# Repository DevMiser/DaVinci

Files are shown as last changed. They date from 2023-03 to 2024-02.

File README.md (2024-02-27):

Raspberry Pi’s newest OS (Bookworm) released on December 5, 2023, does not work well with this installation.
For best results, use a Raspberry Pi 4 (not a Raspberry Pi 5) and use the legacy 64-bit OS.
Instructions are in the Important - Please Read file on this repository.

DaVinci now uses GPT-4.

Feb. 23, 2024 Update - I added an alternative voice to DaVinci that uses OpenAI’s text-to-speech model instead of Amazon Polly.  The alternative file is called DaVinciAltVoice.py.  If you decide to you use this version, you do not need to create an AWS account.  In the rest of the instructions, you can skip “pip3 install boto” and “pip3 install awscli” and all of step 3 for configuring the AWS interface.  Substitute “DaVinciAltVoice.py” for “DaVinci.py” everywhere it appears in the instructions.

I also added an Italian speaking version - DaVinciItalian.py.  To use it, you must follow the additional instructions in the introductory comments in that program.

DaVinci Small








8A
8B
In10
In11
In12

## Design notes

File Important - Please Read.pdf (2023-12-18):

IMPORTANT – PLEASE READ

Raspberry Pi’s newest OS (Bookworm) released on December 5, 2023, does not work well with this installaon.
For best results, use a Raspberry Pi 4 (not a Raspberry Pi 5) and use the legacy 64-bit OS. To load the legacy OS, use Raspberry Pi Imager and select Raspberry Pi 4 as the Raspberry Pi Device. Aer you select CHOOSE OS under Operang System, select Raspberry Pi OS (other) [Figure 1]. On the next screen, scroll down and select Raspberry Pi OS (Legacy, 64-bit) [Figure 2], and proceed as normal from there.

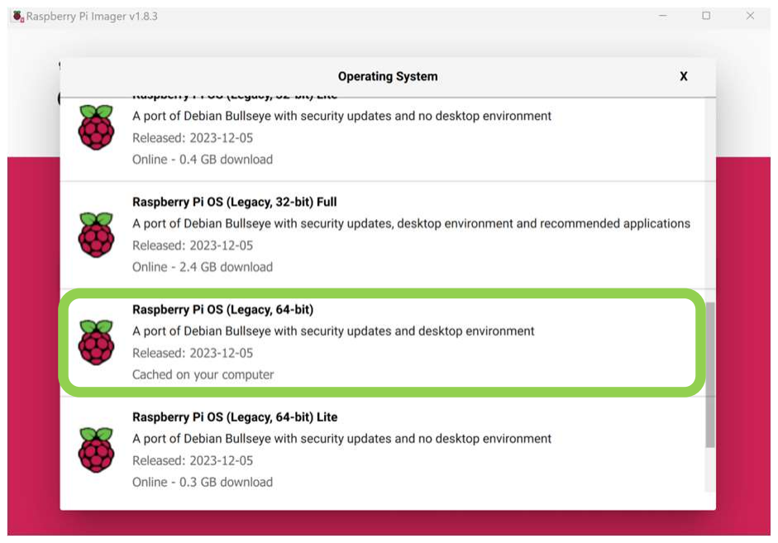
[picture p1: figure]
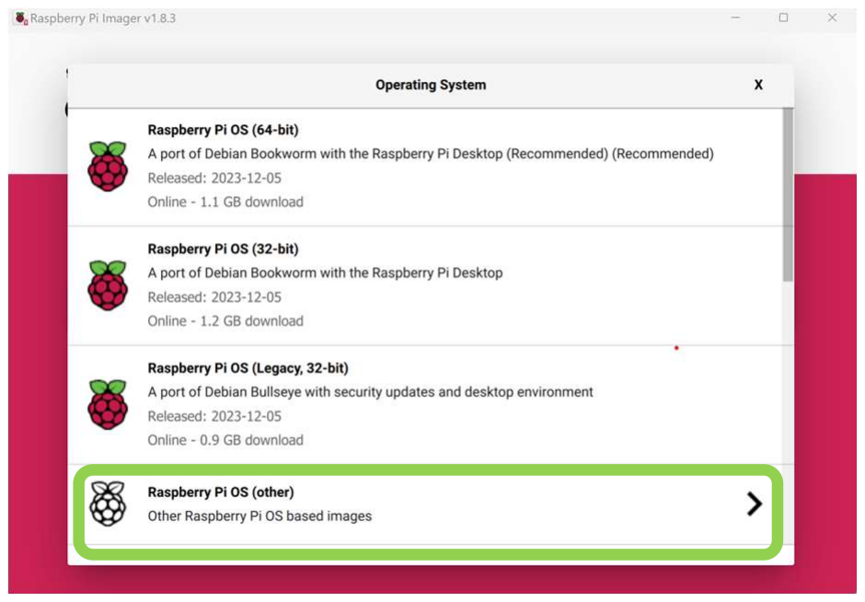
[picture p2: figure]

Figure 1 | Figure 2

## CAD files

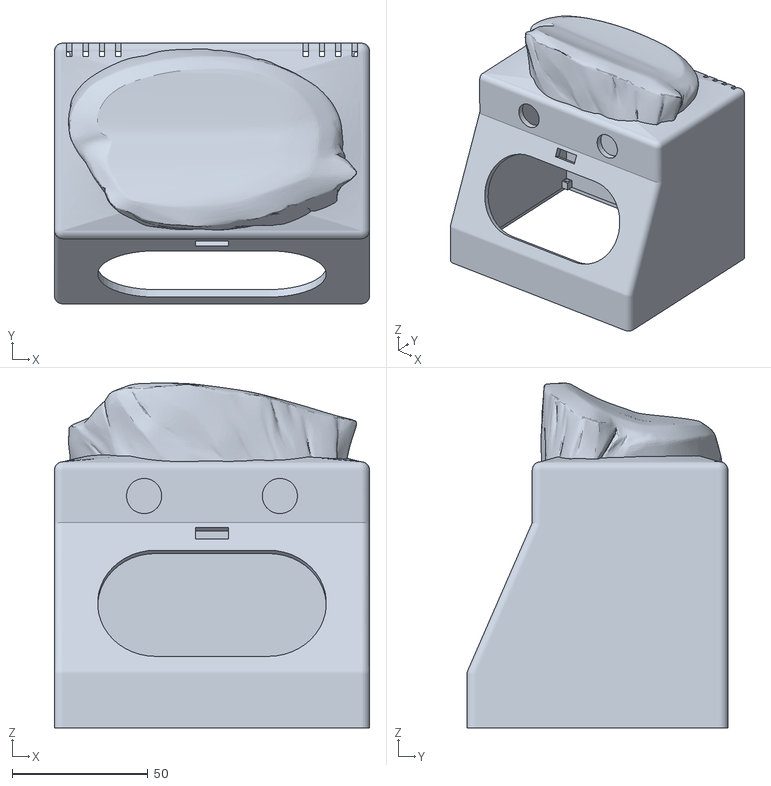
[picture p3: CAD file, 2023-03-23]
DaVinci-Body.stl
116.0 x 96.0 x 127.0

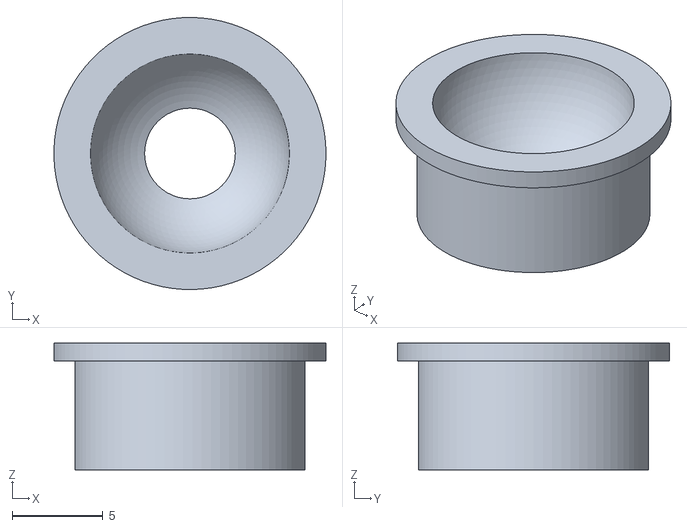
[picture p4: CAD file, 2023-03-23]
DaVinci - EyeSocket.stl
15.0 x 15.0 x 7.00

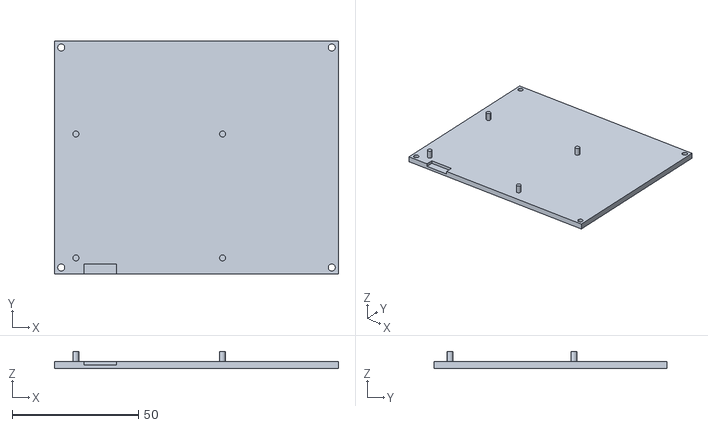
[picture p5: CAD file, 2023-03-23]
DaVinci-BasePlate.stl
112.3 x 92.3 x 6.90

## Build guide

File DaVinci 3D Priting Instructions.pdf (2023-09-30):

## DaVinci 3D Printing Instructions

There are three .stl files on DevMiser GitHub site:

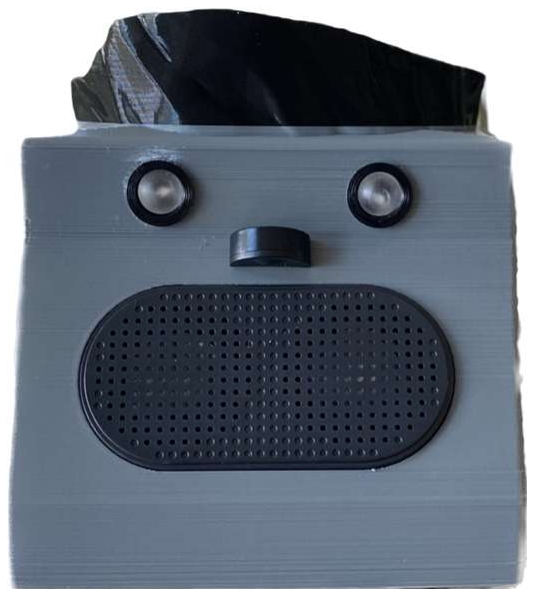
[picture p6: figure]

1. DaVinci-Body.stl – this is the main body that holds the mic, the speaker and the LEDs. Please see the DaVinci – The ChatGPT Virtual Assistant Instructions for a parts list. You will also need an angled USB extension cable that will fit inside the body to connect the mic and speaker. I recommend the following which will allow you to plug the mic and speaker into a single extension cable: https://www.amazon.com/dp/B07ZV7RDNH?psc=1&ref=ppx_yo2ov_dt_b_product_details

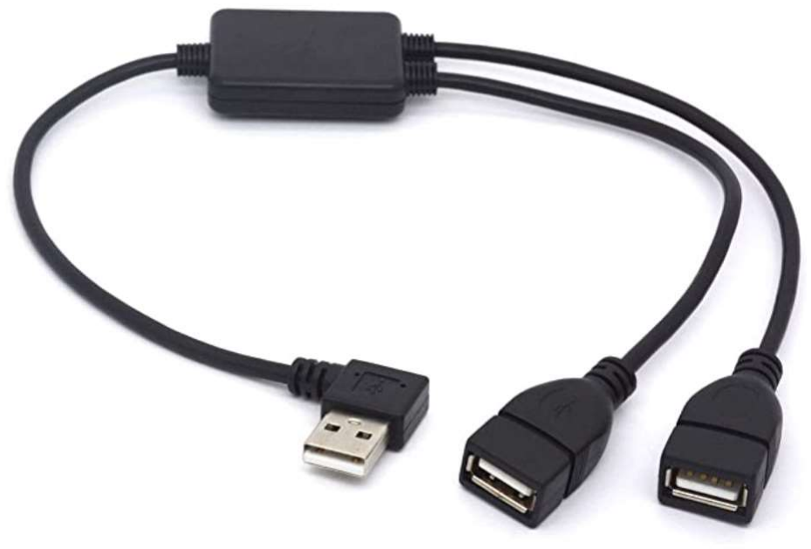
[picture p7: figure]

If you want DaVinci’s hair to be a different color than his body, just insert a change filament instruction at the approximate layer that the hair begins when you use your preferred slicer.
2. DaVinci-BasePlate.stl – this is the bottom part of the body. It has four pegs that the Raspberry Pi 4 will fit onto. You can permanently affix your Pi to the base by putting a little glue at each peg after the Pi is mounted. There is a elliptical hole on the back of the main body for the power supply plug, so be certain to arrange your Pi on the base in the correct direction.

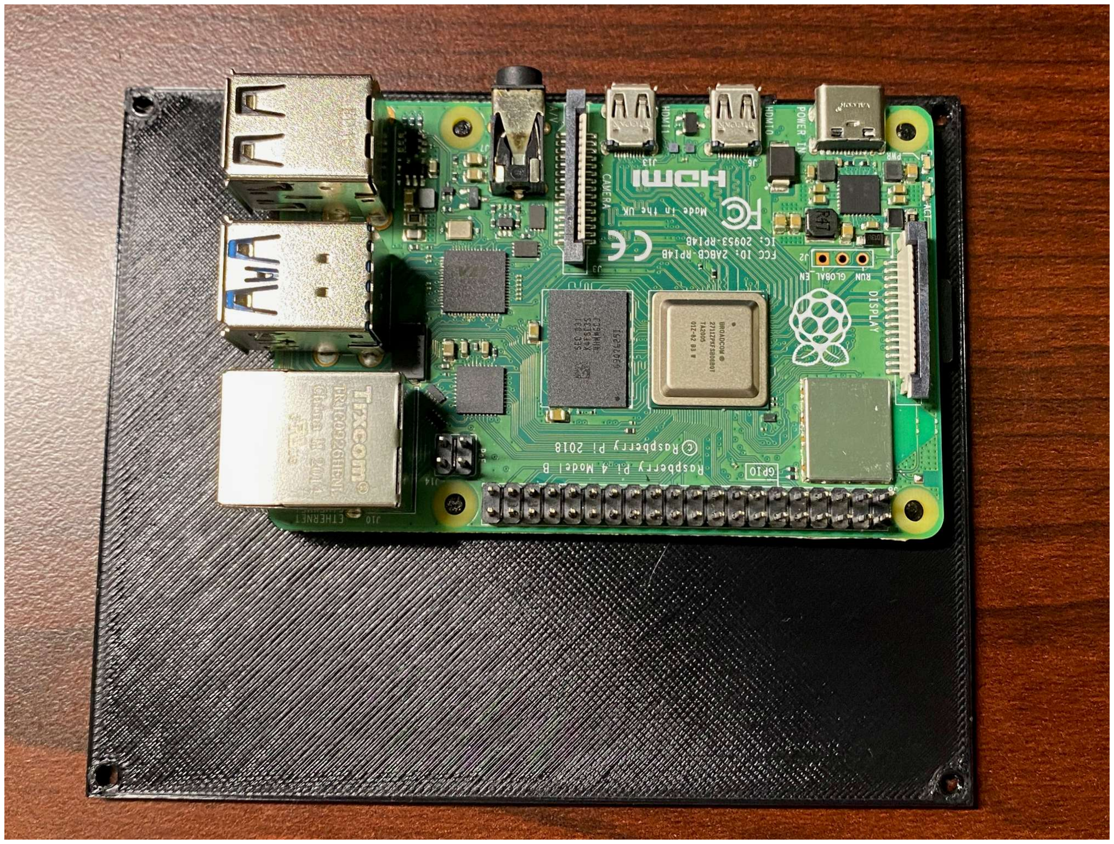
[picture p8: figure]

3. DaVinci-EyeSocket.stl – these fit into the holes for the eyes on the main body and the spherical LEDs will fit inside these sockets. You need to print two of them of course.
You can print the parts with whatever type of filament you prefer, but PLA works fine. I recommend using organic supports for the DaVinci-Body. The DaVinci-BasePlate and DaVinci-EyeSocket do not require supports. The base can be attached to the body with screws (2.5mmx0.45mmx10mm Phillips flat head) or glue.

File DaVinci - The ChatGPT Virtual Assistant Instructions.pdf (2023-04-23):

1

## DaVinci – The ChatGPT Virtual Assistant

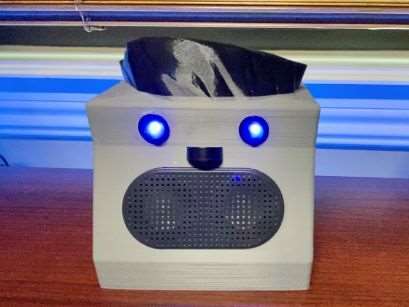
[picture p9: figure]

DaVinci - The ChatGPT virtual assistant is a voice-controlled and voice-response assistant that uses OpenAI’s artificial intelligence language model to assist with a wide range of tasks, such as answering questions, providing information, giving suggestions, telling jokes, writing stories and much more. In addition to providing responses verbally, DaVinci also provide written responses if your device is connected to a display.

Davinci - The ChatGPT virtual assistant is a python program that utilizes Picovoice Porcupine (and (PyAudio) to detect a wake word; Picovoice Cobra voice activity detection to determine when the user begins and finishes speaking their query; Picovoice Leopard to convert the spoken query to text; OpenAI ChatGPT to respond to the query; Amazon Polly text to speech to convert the response into a natural-sounding human voice; and Pygame to play the audio.

DaVinci uses the most current ChatGPT API that was released on March 1, 2023. DaVinci will be updated to run on GPT4 as soon as that API is widely available to developers.

The instructions below are for running the DaVinci – The ChatGPT Virtual Assistant on a Raspberry Pi 4, but it can also be run on other systems with minimal modifications. The process for obtaining access keys for ChatGPT, Picovoice solutions and Amazon Polly is the same regardless of the system used.

You can watch a brief video demo of DaVinci – The ChatGPT Virtual Assistant here: https://youtu.be/r2R4Yoy8XzU

How to Run Davinci on a Raspberry Pi 4 Mini-Computer

The following steps are required to run Davinci - The ChatGPT Virtual Assistant on your Raspberry Pi 4:

- Obtain the necessary hardware
- Create an OpenAI account and obtain your personal secret API key
- Create a Picovoice account and obtain your personal secret access key
- Create an AWS account and obtain your personal access key and secret access key
- Follow the other steps below for preparing your Raspberry Pi and downloading DaVinci - The ChatGPT Virtual Assistant

Note that although account registrations are required to obtain the keys to use the outside services and that production-use of those resources requires the payment of fees, these services should all be free to a user who only utilizes them for the hobbyist requirements of DaVinci - The ChatGPT Virtual Assistant for private use.

2

Hardware Requirements

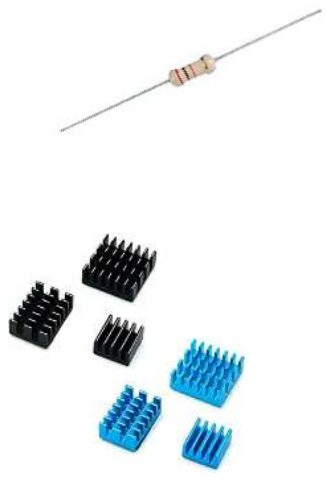
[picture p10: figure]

STLs for the DaVinci 3D-printed enclosure shown in the video demo are also available on this GitHub repository if you have access to a 3D printer and would like to print one.

CAUTION: Raspberry Pi 4s can run hot. If you use an enclosure, make certain that it is properly ventilated and that you use heatsinks or a fan.

Raspberry Pi 4 – This needs to be a Raspberry Pi 4, so that you can run the 64-bit operating system. Earlier versions of Raspberry Pis are likely to throw memory errors while running this program. The 2 GB RAM model is sufficient: https://www.adafruit.com/product/4292

Power Supply – 5v power supply. I recommend the official Raspberry Pi power supply:
https://www.adafruit.com/product/4298

USB Microphone – for talking to the assistant. Any USB mic should work, and this inexpensive one is sufficient: https://www.adafruit.com/product/3367

USB speaker – for the assistant to talk back to you. I used this one: https://www.adafruit.com/product/3369

LEDs (optional) – The program optionally lights LEDs when it detects the wake word and pulses them when it is responding to your queries. These spherical LEDs were used in the video demo: https://www.adafruit.com/product/5430

Resistors (220 ohm) (optional) – Only needed if you decide to use the optional LEDs. I used these:
https://www.adafruit.com/product/2780

Heatsinks (optional) – The heatsinks are optional but are highly recommended if you will put your Raspberry Pi in a case or other confined container such as the one used in the video demo. I used these: https://www.amazon.com/dp/B07ZLZRDXZ?psc=1&smid=A2PL6UUXJC5K5G&ref_=chk_typ_imgToDp

3

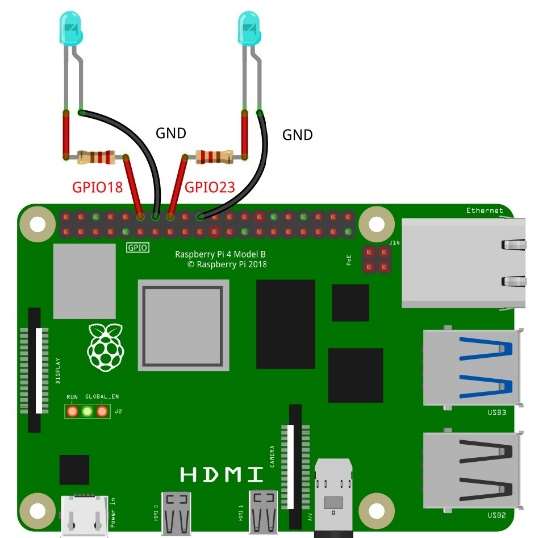
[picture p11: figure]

Optional LED Wiring

Create an OpenAI Account

Open a web browser on your PC and navigate to the OpenAI website -https://openai.com/.

In the upper right-hand corner, click on “API”

On the next screen, click on | and then follow the prompts to create your
account.

Obtain Your Secret OpenAI API Key

Next, on the logged-in screen, click on your Personal icon in the upper right-hand corner and then click on “View API keys”.

DaVinci – The ChatGPT Virtual Assistant includes the ability to light up LEDs that help show the status of the program. If connected, the LEDs will light up when the program hears the wake word and will pulse after the user finishes their query and while the assistant provides its response. The proper wiring of the LEDs and resistors to the Raspberry Pi is shown on this diagram. The LEDs are controlled by GPIO pins 18 and 23. The use of the LEDs is optional and will not otherwise impact the functionality of DaVinci.

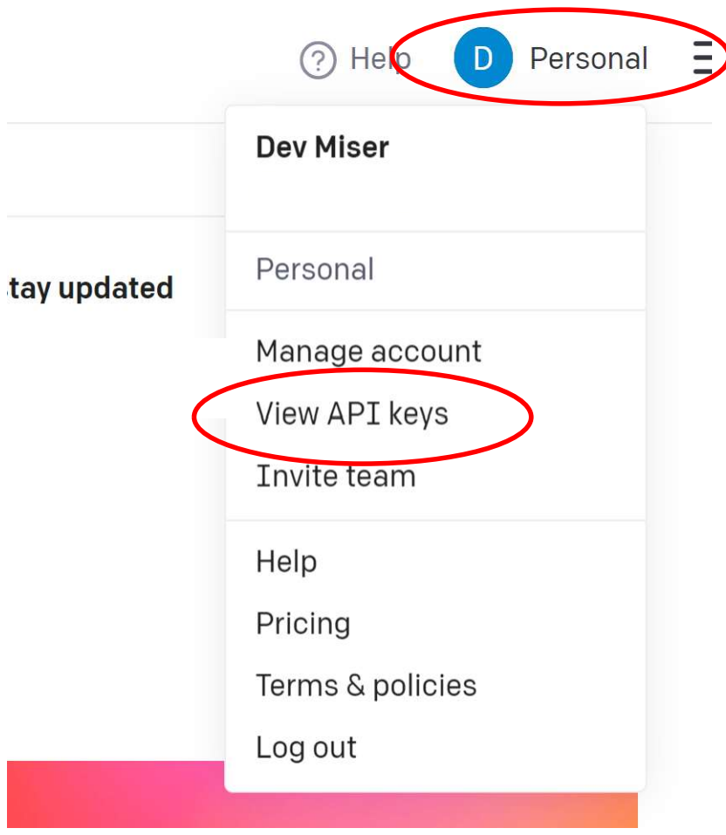
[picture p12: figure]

4

Then click on | to create your new secret API key. Copy your API key
and keep it in a secure location. You will need it in a later step.

Create a Picovoice Account

Create a free Picovoice account. Open a web browser and navigate to https://picovoice.ai/.
In the upper right-hand corner, click the | button and follow the prompts to open
your account.

Obtain Your Secret Picovoice Access Key

As soon as you complete your sign up, you will automatically be redirected to a page
with your secret access key. Copy your | and keep it in a secure location.
You will need it in a later step.

Create an AWS Account

Create a free AWS account. Open a web browser and navigate to the following website to use the AWS Free Tier: https://aws.amazon.com/free/
In the upper right-hand corner, click on the [Complete Si button and follow the prompts to open your account.

Create an AWS IAM User Account and Obtain Your AWS Access Key and Secret Access Key

After you create your AWS account, you will next need to create an IAM User Account on AWS. To do so, follow AWS’s instructions here: https://docs.aws.amazon.com/IAM/latest/UserGuide/getting-set-up.html#create-an-admin

Or you can try the detailed steps in Addendum I. The process is revised occasionally by AWS and may no longer be the same as in the Addendum.

Copy your “Access key” and “Secret access key” and keep them in a secure location. You will need them in a later step.

Prepare Your Raspberry Pi 4 to Run the Program

These instructions assume you already have a Raspberry Pi 4 set up and running. If not, set up your Raspberry Pi using the instructions found here: https://www.raspberrypi.com/tutorials/how-to-set-up-raspberry-pi/

5

Be certain to load the 64-bit (not the 32-bit) version of the Raspberry Pi OS when setting up your Raspberry Pi. If you use the 32-bit version, you are likely to get memory errors when running the program.

To prepare your Raspberry Pi to run DaVinci – The ChatGPT Virtual Assistant, do the following:

### 1. Edit the bashrc file on your Raspberry Pi as follows:

a. Open a terminal and enter the following command to open the bashrc file:

sudo nano ~/.bashrc

b. Scroll to the bottom of the file using your keyboard and add the following lines at the end (be certain to include the #s):

# sets a location where the Raspberry Pi OS and Python can look for

# executable/configuration files

export PATH="$HOME/.local/bin:$PATH"
c. Press the CTRL and X keys simultaneously on your keyboard, then press Y and then press Enter to save the revisions to the file.
d. Then enter the following command:

sudo reboot

This will reboot your Raspberry Pi. After the reboot is completed, log back in.

### 2. Open a terminal and enter the following commands in the following order:

sudo apt update

sudo apt full-upgrade

pip3 install --upgrade pip

sudo apt-get install portaudio19-dev [When asked if you want to continue, enter Y and then press Enter]

pip3 install pyaudio

pip3 install pvrecorder

pip3 install pvporcupine

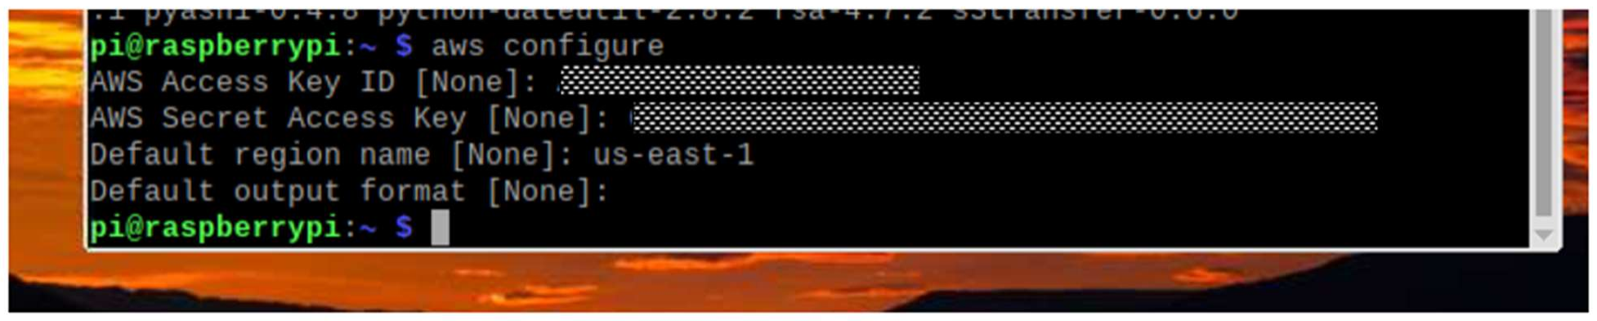
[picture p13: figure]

6

pip3 install pvcobra

pip3 install pvleopard

pip3 install --upgrade openai

pip3 install boto3

pip3 install awscli

sudo reboot – will reboot your Raspberry Pi; log back in after the reboot.

### 3. Configure the AWS command line interface by opening a terminal and entering the

following command:

aws configure

The following lines will appear one-by one. Take the actions specified in the brackets:

AWS Access Key ID [None]: [type in your access key ID and press enter]

AWS Secret Access Key [None]: [type in your secret access key and press enter]

Default region name [None]: [check for the name of the region closest to you here: https://docs.aws.amazon.com/general/latest/gr/rande.html#pol_region – mine is us-east-1 – then type it in and press enter]

Default output format [None]: [leave this blank and press enter]

### 4. Download the DaVinci.py program and associated files by opening a terminal and

entering the following command:

git clone https://github.com/DevMiser/DaVinci.git

### 5. Modify DaVinci.py to include the secret API key that you previously created in your

OpenAI account and the secret access key that you created in your Picovoice account by doing the following:

7

a. Open a terminal and enter the following commands:

cd /home/pi/DaVinci

sudo nano DaVinci.py

b. Use your keyboard to scroll down to the lines that say:

openai.api_key = “put your secret API key between these quotation marks” pv_access_key= “put your secret access key between these quotation marks”

Now modify those lines to replace the portions that are italicized above with your secret OpenAI API key and your secret Picovoice access key, respectively.

c. Press the CTRL and X keys simultaneously on your keyboard, then press Y and then press Enter to save the revisions to the file.

### 6. Move the DaVinci keyword file to the Porcupine raspberry-pi folder by entering the

following command:

mv /home/pi/DaVinci/DaVinci_raspberry-pi.ppn /home/pi/.local/lib/python3.9/site-packages/pvporcupine/resources/keyword_files/raspberry-pi

7. Reboot your Raspberry Pi.

Run the Program

Plug your microphone and speaker into USB ports on your Raspberry Pi 4.

To run the program, open a terminal and enter the following commands:

cd /home/pi/DaVinci

python3 DaVinci.py

You can then wake up your ChatGPT Virtual Assistant by saying one of the following wake words: DaVinci, computer or Jarvis.

DaVinci – The ChatGPT Virtual Assistant will respond by saying “How may I assist you?”, “I’m listening.” or something similar.

Then make your request. For example, say:

Describe purple.

8

What is the difference between pumas and leopards?

What are the most popular tourist attractions in Tel Aviv?

What would happen if the moon disappeared?

What can you do?

Write a silly dialogue between a stapler and a coffee mug.

What is the plot of To Kill a Mockingbird?

What is the meaning of the song Stairway to Heaven by Led Zeppelin.

Tell me a story about a mouse named Mike who is looking for his lost cheese in the Astrodome.

What are the top 5 foods that should be included in a healthy diet.

Make a joke about dancing robots.

How can I avoid procrastinating today?

Write a short poem about artificial intelligence.

When you are finished with the program, press the CTRL and C keys simultaneously on your keyboard and you will exit the program.

© 2023 DevMiser. All rights reserved.

1

Addendum I

AWS Identity and Management Access (IAM) Dashboard Instructions

The following instructions are how to to create an IAM User Account on AWS. This process is revised occasionally by AWS and may no longer be exactly the same as in this Addendum. You can check AWS’s documentation for the most current instructions.

After you create your AWS account, sign in and go to the Identify and Manage Access (IAM) dashboard at this url: https://console.aws.amazon.com/iamv2

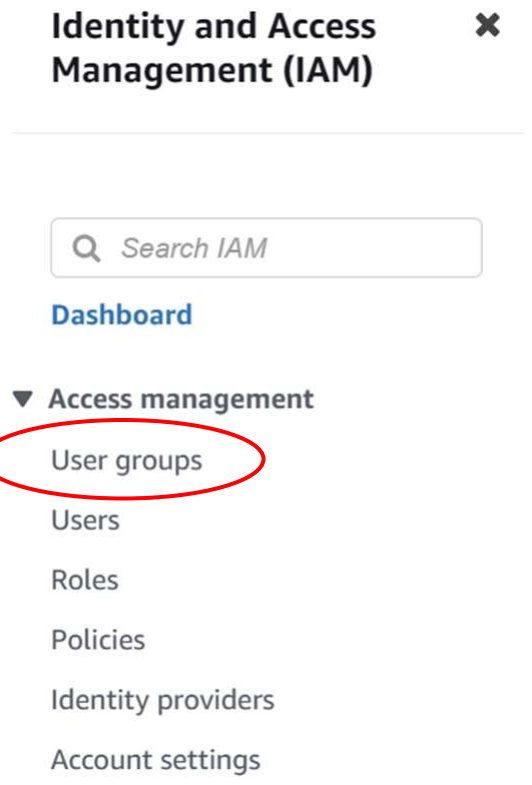
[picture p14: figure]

2. On the next page, enter ”Polly” into the box underneath “User group name “.

### 3. Further down on the same page in the box that says “Attach permissions policies –

Optional”, search for “Polly” and then select “AmazonPollyFullAccess” from the search results.
4. Next select “Users” from the left-hand menu.

### 5. Click “Add users” from the upper right-hand corner and type “Polly_User” in the box

under “User name” and click “Next”.

### 6. On the next page under Permission options, select “Add user to group” and check the

box next to “Polly” under “User groups”, and then click “Next”.
7. On the next page, click “Create Us .

### 8. On the next page, click the “View User” button:

### 1. Select “User groups” from the

menu on the left-hand side and then click “Create Gro in the upper right-hand corner.

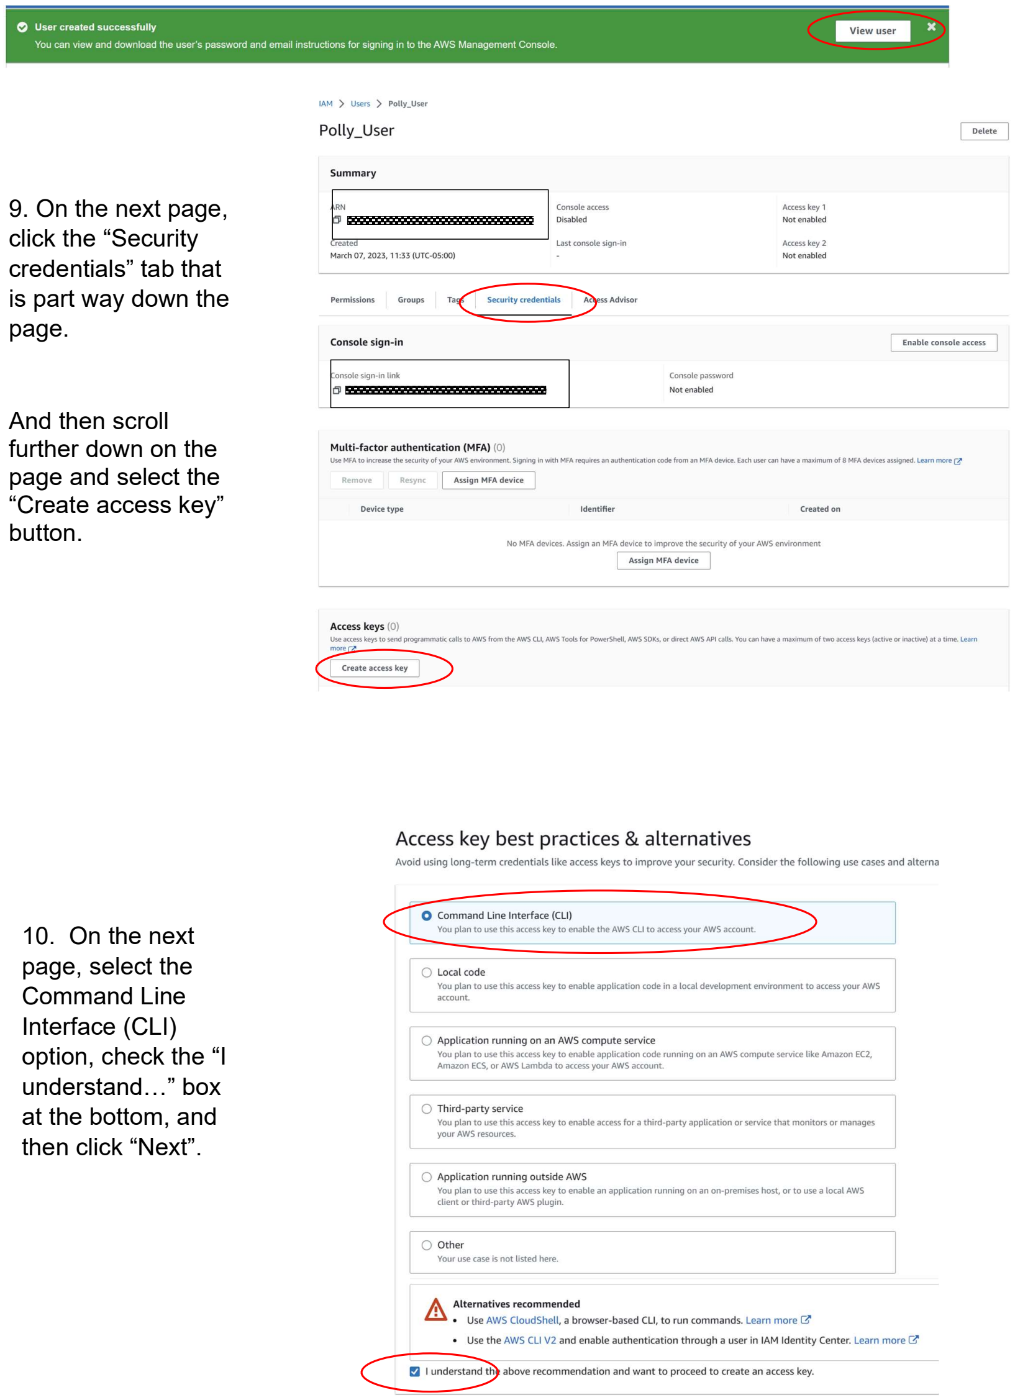
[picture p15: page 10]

2

9. On the next page,
click the “Security
credentials” tab that
is part way down the
page.

And then scroll
further down on the
page and select the
“Create access key”
button.

### 10. On the next

page, select the
Command Line
Interface (CLI)
option, check the “I
understand…” box
at the bottom, and
then click “Next”.

3

11. On the next page, leave it blank and click “Create Access .
12. The next page will be headed “Retrieve access keys”.
Copy both the “Access key” and “Secret access key” and keep them in a secure location. This is the only time that the secret access key can be viewed or downloaded. If you lose it, you will need to create a new access key and make the old one inactive.

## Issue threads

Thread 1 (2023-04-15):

Issue with outdated keyword file

thatbitchsystem, 2023-04-15:
Terminal output when attempting to run the program after fresh install

pi@raspberrypi:~/DaVinci $ python3 DaVinci.py
[ERROR] keyword file belongs to a different version of the library. keyword file is `2.1.0` while the library is                                                                                                                 `2.2.0`.
[ERROR] loading keyword file at `/home/pi/.local/lib/python3.9/site-packages/pvporcupine/resources/keyword_files/                                                                                                                raspberry-pi/DaVinci_raspberry-pi.ppn` failed with `INVALID_ARGUMENT`
Traceback (most recent call last):
  File "/home/pi/DaVinci/DaVinci.py", line 288, in <module>
    wake_word()
  File "/home/pi/DaVinci/DaVinci.py", line 142, in wake_word
    porcupine = pvporcupine.create(keywords=["computer", "jarvis", "DaVinci",],
  File "/home/pi/.local/lib/python3.9/site-packages/pvporcupine/_factory.py", line 69, in create
    return Porcupine(
  File "/home/pi/.local/lib/python3.9/site-packages/pvporcupine/_porcupine.py", line 164, in __init__
    raise self._PICOVOICE_STATUS_TO_EXCEPTION[status]()
pvporcupine._porcupine.PorcupineInvalidArgumentError
^CException ignored in: <module 'threading' from '/usr/lib/python3.9/threading.py'>
Traceback (most recent call last):
  File "/usr/lib/python3.9/threading.py", line 1428, in _shutdown
    lock.acquire()
KeyboardInterrupt:

thatbitchsystem, 2023-04-15:
Resolved issue with the following commands:
$ mv /home/pi/.local/lib/python3.9/site-packages/pvporcupine/resources/keyword_files/raspberry-pi/DaVinci_raspberry-pi.ppn /home/pi/DaVinci/
$ pip3 uninstall pvporcupine
$ pip3 install pvporcupine==2.1.0
$  mv /home/pi/DaVinci/DaVinci_raspberry-pi.ppn /home/pi/.local/lib/python3.9/site-packages/pvporcupine/resources/keyword_files/raspberry-pi
$ python3 DaVinci.py

DevMiser, 2023-06-20:
The keyword file is now updated

Closed 2023-09-26.

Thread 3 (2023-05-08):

Issue with moving the files

ProfileNameIsOk, 2023-05-08:
Step 6 in the read me file has been bugging me a bit. I've done all the correct prompts and created the correct accounts. However, when I type this final command I'm met with "mv: cannot move '/home/pi/DaVinci/Davinci_raspberry-pi.ppn' to '/home/pi/.local/lib/python3.9/site-packages/pvporcupine/resources/keyword_files/raspberry-pi': no such file or directory"

Any help will be greatly appreciated!

DevMiser, 2023-05-08:
Here is the command that hopefully you can cut and paste:

mv /home/pi/DaVinci/DaVinci_raspberry-pi.ppn /home/pi/.local/lib/python3.9/site-packages/pvporcupine/resources/keyword_files/raspberry-pi

Note that there should be two blank spaces in your command - between "mv" and "/home" and between ".ppn" and "/home". Be sure to include them. There is no space in "site-packages".

ProfileNameIsOk, 2023-05-08:
Thank you for the help! The command worked, I appreciate it greatly

Closed 2023-05-08.

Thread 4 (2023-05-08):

Quick question regarding OpenAI

ProfileNameIsOk, 2023-05-08:
Hi there

I set up DaVinci and it seems to be fully working. However, when I ask a question it says that openai has exceeded my current quota. So I applied for a pay as you go method. How long does it take for the api to work on the raspberry pi 4 again? Am I doing something wrong?

Closed 2023-05-08.

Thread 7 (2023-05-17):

ALSA lib pcm_dsnoop.c:638:(snd_pcm_dsnoop_open) unable to open slave

t0mer, 2023-05-17:
Hi,
First, let me thank you for your great work.
I'm trying to use the script on Rpi 3 with a USB mic. and I'm getting the following error after the wake up response:

```ALSA lib pcm_dsnoop.c:638:(snd_pcm_dsnoop_open) unable to open slave
ALSA lib pcm_dsnoop.c:638:(snd_pcm_dsnoop_open) unable to open slave
ALSA lib pcm_dsnoop.c:638:(snd_pcm_dsnoop_open) unable to open slave
ALSA lib pcm_dsnoop.c:638:(snd_pcm_dsnoop_open) unable to open slave
ALSA lib pcm_dsnoop.c:638:(snd_pcm_dsnoop_open) unable to open slave
ALSA lib pcm_dsnoop.c:638:(snd_pcm_dsnoop_open) unable to open slave
Expression 'ret' failed in 'src/hostapi/alsa/pa_linux_alsa.c', line: 1736
Expression 'AlsaOpen( &alsaApi->baseHostApiRep, params, streamDir, &self->pcm )' failed in 'src/hostapi/alsa/pa_linux_alsa.c', line: 1904
Expression 'PaAlsaStreamComponent_Initialize( &self->capture, alsaApi, inParams, StreamDirection_In, NULL != callback )' failed in 'src/hostapi/alsa/pa_linux_alsa.c', line: 2171
Expression 'PaAlsaStream_Initialize( stream, alsaHostApi, inputParameters, outputParameters, sampleRate, framesPerBuffer, callback, streamFlags, userData )' failed in 'src/hostapi/alsa/pa_linux_alsa.c', line: 2839
Traceback (most recent call last):
  File "/opt/webplant/app.py", line 311, in <module>
    listen()
  File "/opt/webplant/app.py", line 205, in listen
    listen_audio_stream = listen_pa.open(
  File "/usr/lib/python3/dist-packages/pyaudio.py", line 750, in open
    stream = Stream(self, *args, **kwargs)
  File "/usr/lib/python3/dist-packages/pyaudio.py", line 441, in __init__
    self._stream = pa.open(**arguments)
OSError: [Errno -9985] Device unavailable```

Any thoughts?

Thanks

Closed 2023-05-17.

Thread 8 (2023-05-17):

Failed to initialize pv_recorder

t0mer, 2023-05-17:
Hi,
I am running on Rpi 4 with 4G memory, 128GB sd card, and 64bit os.
The Wakeup word is working, but second after the response, I'm getting the following error:

```Traceback (most recent call last):
  File "/usr/lib/python3.9/threading.py", line 954, in _bootstrap_inner
    self.run()
  File "/opt/webplant/app.py", line 281, in run
    recorder = PvRecorder(device_index=-1, frame_length=1024)
  File "/usr/local/lib/python3.9/dist-packages/pvrecorder/pvrecorder.py", line 81, in __init__
    raise self._PVRECORDER_STATUS_TO_EXCEPTION[status]("Failed to initialize pv_recorder.")
RuntimeError: Failed to initialize pv_recorder.
```

Thanks

jimbo0378, 2023-06-07:
Did you find a solution? I'm running into the same issue

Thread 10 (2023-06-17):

Is it necessary to excute the codes every time to start davinci

armornet, 2023-06-17:
Hello,
       As per your instructions is it necessary to execute the code
python3 DaVinci.py

everytime in the rasberry pi so that the davinci works...

In your video it seems automatic

DevMiser, 2023-06-17:
No, you only need to execute the code once and it will run continuously.  What error code do you get when it stops working?  If the error relates to memory, please make certain that you are using a Raspberry Pi 4 and using the 64-bit operating system.

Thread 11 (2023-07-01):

Connection issues after saying keyword

repcop, 2023-07-01:
Hi DevMiser,
thanks for this excellent work and instructions for use.
I installed everything acc your instructions- and getting the following fail messages, after saying the keyword:

Wake word detected

Traceback (most recent call last):
  File "/usr/lib/python3/dist-packages/urllib3/connection.py", line 169, in _new_conn
    conn = connection.create_connection(
  File "/usr/lib/python3/dist-packages/urllib3/util/connection.py", line 73, in create_connection
    for res in socket.getaddrinfo(host, port, family, socket.SOCK_STREAM):
  File "/usr/lib/python3.9/socket.py", line 953, in getaddrinfo
    for res in _socket.getaddrinfo(host, port, family, type, proto, flags):
socket.gaierror: [Errno -2] Name or service not known

Can you help me please?
BR,
Andreas

DevMiser, 2023-07-01:
Hi Andreas.  It seems that you are trying to connect to a server that is not reachable. Because the next function called after the wake word is the voice for DaVinci's greeting, I suspect that your RPi is not connecting to the AWS server.  I recommend redoing step 3 on page 6 of the instructions and make certain to use the correct region name (as determined by reviewing the service endpoint information at https://docs.aws.amazon.com/general/latest/gr/rande.html#pol_region).  I hope this helps.  If not, I recommend redoing the AWS IAM and making certain that you enter your AWS access key ID and secret access key correctly.

repcop, 2023-07-02:
Hi DevMiser, thanks very much, indeed the AWS server was the problem. I changed from eu-central-2 to eu-central-1, and now it works!

Closed 2023-07-02.

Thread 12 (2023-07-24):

Alot of traceback errors

theson122333, 2023-07-24:
I am doing this for a school project as part of my final. soon as I try and use it
Wake word detected

Traceback (most recent call last):
  File "/usr/lib/python3/dist-packages/urllib3/connection.py", line 169, in _new_conn
    conn = connection.create_connection(
  File "/usr/lib/python3/dist-packages/urllib3/util/connection.py", line 73, in create_connection
    for res in socket.getaddrinfo(host, port, family, socket.SOCK_STREAM):
  File "/usr/lib/python3.9/socket.py", line 953, in getaddrinfo
    for res in _socket.getaddrinfo(host, port, family, type, proto, flags):
socket.gaierror: [Errno -2] Name or service not known

During handling of the above exception, another exception occurred:

Traceback (most recent call last):
  File "/home/medwards/.local/lib/python3.9/site-packages/botocore/httpsession.py", line 465, in send
    urllib_response = conn.urlopen(
  File "/usr/lib/python3/dist-packages/urllib3/connectionpool.py", line 755, in urlopen
    retries = retries.increment(
  File "/usr/lib/python3/dist-packages/urllib3/util/retry.py", line 507, in increment
    raise six.reraise(type(error), error, _stacktrace)
  File "/usr/lib/python3/dist-packages/six.py", line 719, in reraise
    raise value
  File "/usr/lib/python3/dist-packages/urllib3/connectionpool.py", line 699, in urlopen
    httplib_response = self._make_request(
  File "/usr/lib/python3/dist-packages/urllib3/connectionpool.py", line 382, in _make_request
    self._validate_conn(conn)
  File "/usr/lib/python3/dist-packages/urllib3/connectionpool.py", line 1012, in _validate_conn
    conn.connect()
  File "/usr/lib/python3/dist-packages/urllib3/connection.py", line 353, in connect
    conn = self._new_conn()
  File "/usr/lib/python3/dist-packages/urllib3/connection.py", line 181, in _new_conn
    raise NewConnectionError(
urllib3.exceptions.NewConnectionError: <botocore.awsrequest.AWSHTTPSConnection object at 0xdfbcbe68>: Failed to establish a new connection: [Errno -2] Name or service not known

During handling of the above exception, another exception occurred:

Traceback (most recent call last):
  File "/home/medwards/DaVinci/DaVinci.py", line 294, in <module>
    voice(random.choice(prompt))
  File "/home/medwards/DaVinci/DaVinci.py", line 99, in voice
    voiceResponse = polly.synthesize_speech(Text=chat, OutputFormat="mp3",
  File "/home/medwards/.local/lib/python3.9/site-packages/botocore/client.py", line 534, in _api_call
    return self._make_api_call(operation_name, kwargs)
  File "/home/medwards/.local/lib/python3.9/site-packages/botocore/client.py", line 959, in _make_api_call
    http, parsed_response = self._make_request(
  File "/home/medwards/.local/lib/python3.9/site-packages/botocore/client.py", line 982, in _make_request
    return self._endpoint.make_request(operation_model, request_dict)
  File "/home/medwards/.local/lib/python3.9/site-packages/botocore/endpoint.py", line 119, in make_request
    return self._send_request(request_dict, operation_model)
  File "/home/medwards/.local/lib/python3.9/site-packages/botocore/endpoint.py", line 202, in _send_request
    while self._needs_retry(
  File "/home/medwards/.local/lib/python3.9/site-packages/botocore/endpoint.py", line 354, in _needs_retry
    responses = self._event_emitter.emit(
  File "/home/medwards/.local/lib/python3.9/site-packages/botocore/hooks.py", line 412, in emit
    return self._emitter.emit(aliased_event_name, **kwargs)
  File "/home/medwards/.local/lib/python3.9/site-packages/botocore/hooks.py", line 256, in emit
    return self._emit(event_name, kwargs)
  File "/home/medwards/.local/lib/python3.9/site-packages/botocore/hooks.py", line 239, in _emit
    response = handler(**kwargs)
  File "/home/medwards/.local/lib/python3.9/site-packages/botocore/retryhandler.py", line 207, in __call__
    if self._checker(**checker_kwargs):
  File "/home/medwards/.local/lib/python3.9/site-packages/botocore/retryhandler.py", line 284, in __call__
    should_retry = self._should_retry(
  File "/home/medwards/.local/lib/python3.9/site-packages/botocore/retryhandler.py", line 320, in _should_retry
    return self._checker(attempt_number, response, caught_exception)
  File "/home/medwards/.local/lib/python3.9/site-packages/botocore/retryhandler.py", line 363, in __call__
    checker_response = checker(
  File "/home/medwards/.local/lib/python3.9/site-packages/botocore/retryhandler.py", line 247, in __call__
    return self._check_caught_exception(
  File "/home/medwards/.local/lib/python3.9/site-packages/botocore/retryhandler.py", line 416, in _check_caught_exception
    raise caught_exception
  File "/home/medwards/.local/lib/python3.9/site-packages/botocore/endpoint.py", line 281, in _do_get_response
    http_response = self._send(request)
  File "/home/medwards/.local/lib/python3.9/site-packages/botocore/endpoint.py", line 377, in _send
    return self.http_session.send(request)
  File "/home/medwards/.local/lib/python3.9/site-packages/botocore/httpsession.py", line 494, in send
    raise EndpointConnectionError(endpoint_url=request.url, error=e)
botocore.exceptions.EndpointConnectionError: Could not connect to the endpoint URL: "https://polly.editing.amazonaws.com/v1/speech"
^CException ignored in: <module 'threading' from '/usr/lib/python3.9/threading.py'>
Traceback (most recent call last):
  File "/usr/lib/python3.9/threading.py", line 1428, in _shutdown
    lock.acquire()
KeyboardInterrupt:

DevMiser, 2023-07-25:
It looks like your errors may be originating from AWS Polly.  I would retry the following command in a terminal:
pip3 install boto3
If that does not work, check your version of Python by entering the following command in a terminal:
python --version
If it does not return Python 3.8 or later, you will need to update to a newer version of Python.
If that does not work, check this documentation: https://boto3.amazonaws.com/v1/documentation/api/latest/guide/quickstart.html
I hope that helps.

theson122333, 2023-07-25:
i tried installing boto3, said it was already there
It shows im using python version 3.9.2
i tried installing everything again to make sure I got everything. After running again and eltting it go for a litlte while, i got this message
botocore.exceptions.EndpointConnectionError: Could not connect to the endpoint URL: "https://polly/editing.amazonaws.com/v1/speech"
Maybe I typed in the accces key incorrectly? im trying to figure out how to retype them in the terminal
Thank you for helping me with this, I appreciate your time

DevMiser, 2023-07-26:
From this error, it appears you may be trying to connect to an incorrect or invalid endpoint URL for the Polly service.  Check whether you are using the default region name closest to you here: https://docs.aws.amazon.com/general/latest/gr/rande.html#pol_region

theson122333, 2023-07-31:
I got it working. I retyped in all the access keys and redid the region name and got it to work Thank you so much for your hard work on this.
Also wondering, how do you get this to work without using a monitor? I noticed you have to use the terminal to turn it on. Do you turn it on, unplug everything then just let it run?
Again thank you so much. This was a very fun project and its really cool

DevMiser, 2023-08-04:
I am happy to hear that you got it working!
Yes, you do need a monitor to start the program.  You can then unplug it.  You may want to enable VNC or SSH on your Raspberry Pi so that you can log onto it remotely via Wi-Fi with a PC instead of physically attaching a monitor to the Pi.

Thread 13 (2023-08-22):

A few errors...

OzRoyalOG, 2023-08-22:
So the script recognises the wake word and then listens... When I ask a question I get the following errors...

You have hit your assigned rate limit.
Traceback (most recent call last):
  File "/home/ozroyalog/DaVinci/DaVinci.py", line 306, in <module>
    (res) = ChatGPT(transcript)
  File "/home/ozroyalog/DaVinci/DaVinci.py", line 71, in ChatGPT
    response = openai.ChatCompletion.create(
  File "/home/ozroyalog/.local/lib/python3.9/site-packages/openai/api_resources/chat_completion.py", line 25, in create
    return super().create(*args, **kwargs)
  File "/home/ozroyalog/.local/lib/python3.9/site-packages/openai/api_resources/abstract/engine_api_resource.py", line 153, in create
    response, _, api_key = requestor.request(
  File "/home/ozroyalog/.local/lib/python3.9/site-packages/openai/api_requestor.py", line 298, in request
    resp, got_stream = self._interpret_response(result, stream)
  File "/home/ozroyalog/.local/lib/python3.9/site-packages/openai/api_requestor.py", line 700, in _interpret_response
    self._interpret_response_line(
  File "/home/ozroyalog/.local/lib/python3.9/site-packages/openai/api_requestor.py", line 763, in _interpret_response_line
    raise self.handle_error_response(
openai.error.RateLimitError: Your account is not active, please check your billing details on our website.

During handling of the above exception, another exception occurred:

Traceback (most recent call last):
  File "/home/ozroyalog/DaVinci/DaVinci.py", line 345, in <module>
    voice("\nYou have hit your assigned rate limit.")
  File "/home/ozroyalog/DaVinci/DaVinci.py", line 100, in voice
    voiceResponse = polly.synthesize_speech(Text=chat, OutputFormat="mp3",
  File "/home/ozroyalog/.local/lib/python3.9/site-packages/botocore/client.py", line 535, in _api_call
    return self._make_api_call(operation_name, kwargs)
  File "/home/ozroyalog/.local/lib/python3.9/site-packages/botocore/client.py", line 980, in _make_api_call
    raise error_class(parsed_response, operation_name)
botocore.exceptions.ClientError: An error occurred (InvalidSignatureException) when calling the SynthesizeSpeech operation: The request signature we calculated does not match the signature you provided. Check your AWS Secret Access Key and signing method. Consult the service documentation for details.

All the Access Keys, APi keys etc are correct... Any ideas?

OzRoyalOG, 2023-08-22:
So as an update on this... I am now getting an initial response from ChatGPT when running the script. But I also get this error too and no sound...

Exception in thread Thread-12:
Traceback (most recent call last):
  File "/usr/lib/python3.9/threading.py", line 954, in _bootstrap_inner
    self.run()
  File "/usr/lib/python3.9/threading.py", line 892, in run
    self._target(*self._args, **self._kwargs)
  File "/home/ozroyalog/DaVinci/DaVinci.py", line 100, in voice
    voiceResponse = polly.synthesize_speech(Text=chat, OutputFormat="mp3",
  File "/home/ozroyalog/.local/lib/python3.9/site-packages/botocore/client.py", line 535, in _api_call
    return self._make_api_call(operation_name, kwargs)
  File "/home/ozroyalog/.local/lib/python3.9/site-packages/botocore/client.py", line 980, in _make_api_call
    raise error_class(parsed_response, operation_name)
botocore.exceptions.ClientError: An error occurred (InvalidSignatureException) when calling the SynthesizeSpeech operation: The request signature we calculated does not match the signature you provided. Check your AWS Secret Access Key and signing method. Consult the service documentation for details.

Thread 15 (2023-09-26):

Issue with wake word / keyword file

mrpundir, 2023-09-26:
Terminal output is as follows(on fresh install):

sudo python3 DaVinci.py
Traceback (most recent call last):
  File "/home/rickkpr/DaVinci/DaVinci.py", line 295, in <module>
    wake_word()
  File "/home/rickkpr/DaVinci/DaVinci.py", line 146, in wake_word
    porcupine = pvporcupine.create(keywords=["computer", "jarvis", "DaVinci",],
  File "/usr/local/lib/python3.10/dist-packages/pvporcupine/__init__.py", line 67, in create
    raise ValueError(
ValueError: One or more keywords are not available by default. Available default keywords are:\npicovoice, computer, grasshopper, hey barista, terminator, ok google, hey siri, bumblebee, grapefruit, jarvis, hey google, pico clock, porcupine, alexa, americano, blueberry
^CException ignored in: <module 'threading' from '/usr/lib/python3.10/threading.py'>
Traceback (most recent call last):
  File "/usr/lib/python3.10/threading.py", line 1567, in _shutdown
    lock.acquire()
KeyboardInterrupt:

I also tried using the below resolution, but it did not worked for me:

[thatbitchsystem](https://github.com/thatbitchsystem) commented [on Apr 16](https://github.com/DevMiser/DaVinci/issues/1#issuecomment-1509993307)
Resolved issue with the following commands:
$ mv /home/pi/.local/lib/python3.9/site-packages/pvporcupine/resources/keyword_files/raspberry-pi/DaVinci_raspberry-pi.ppn /home/pi/DaVinci/
$ pip3 uninstall pvporcupine
$ pip3 install pvporcupine==2.1.0
$ mv /home/pi/DaVinci/DaVinci_raspberry-pi.ppn /home/pi/.local/lib/python3.9/site-packages/pvporcupine/resources/keyword_files/raspberry-pi
$ python3 DaVinci.py

Please note, in the above step/resolution, the file is named 'DaVinci_raspberry-pi.ppn' [single underscore in file name] however, in the latest build available, the file is named 'DaVinci__raspberry-pi.ppn' with two consecutive underscore in the name of file. I tried the above resolution and/or also tried to rename the file to 'DaVinci_raspberry-pi.ppn', but still it does not work. Please point me to the right direction/should I downgrade my python version to 3.9

FYI - my python version is 3.10, so I made the changes to the path accordingly. Thanks.

DevMiser, 2023-09-26:
You should also reinstall the current version of pvporcupine.

mrpundir, 2023-09-28:
1 - Took care of this part: 'please note that there are two blank spaces in the above command - between "mv" and "/home" and between ".ppn" and "/home". Be sure to include them'
2 - Took care of this as well: 'You should also reinstall the current version of pvporcupine'

Still, getting same error. FYI - my OS is Ubuntu 22.04.3 LTS (Jammy Jellyfish) on Raspberry Pi 4 with python version 3.10
I have still not tried downgrading the python version down to 3.9.3 Please let me know if the issue is there with Ubuntu OS maybe(aarch64). Thanks again for your prompt reply earlier. Waiting up to hear more from you, will keep you updated as well.

BerkSmash1984, 2023-10-06:
I am getting the same error regarding the wake word, as of 10/6 with a fresh install of DaVinci on a freshly flashed DietPi OS on my RPI4B:

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

The latest version of DietPi OS (v8.22.3) has Python 3.11 installed. Any ideas?

DevMiser, 2023-10-07:
I recommend trying the following:
Modify the DaVinci.py file by deleting the word "Davinci" from line 146 so that it now reads "porcupine = pvporcupine.create(keywords=["computer", "jarvis",],"
Also delete one of the "0.1"s from line 148 so that it now reads:  "sensitivities=[0.1, 0.1],"
And then try waking it up by saying either "computer" or "jarvis"
If you continue to get an error that includes "One or more keywords are not available by default...", then there is likely  an issue with where the keyword file is located in your directories that you will need to track down
If there is an error that does not include that phrase, it could be a host of things including that there may be dependencies not included in DietPi OS.  I would then recommend using the official Raspberry Pi 64-bit OS.  https://www.raspberrypi.com/software/ Make certain to use the 64-bit version.  DaVinci will word correctly if you do so and follow the instructions exactly.
Good luck and I hope you get it working.

mrpundir, 2023-10-08:
@BerkSmash1984 Thanks for chiming in, and please do let me know if the above reply from @DevMiser was able to resolve the issue. I am on a trip outside and may not be able to check right away on my Raspberry Pi setup(with Ubuntu OS 64 bit). Much thanks to both of you :)

BerkSmash1984, 2023-10-08:
I definitely will. I'm currently out of town but will give it a go when I return. I wish I had just stuck to Bullseye OS but DietPi sounded fun. I'll give the recommendation a go and then likely reflash to Bullseye. Unfortunately I will also have to redo my PiHole and MagicMirror, as everything is running on this Pi 🙃

mrpundir, 2023-10-10:
Finally, it seems like the issue is with OS compatibility only.

This project will work with Raspberry Pi OS(Bullseye) only, and is not compatible with other 64bit OS like Ubuntu 22.04.3 LTS OS, or DietPi OS, etc. due to missing dependencies maybe(OS specific).

May try in future with Bullseye OS. Closing the raised issue now.

Thanks all :)

Closed 2023-10-10.

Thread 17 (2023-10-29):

Picovoice status to exception; keyword file 2.2 v 3.0; and wake word error

Scitech123, 2023-10-29:
Excellent instructions. I'm hung up on just these few things. Any suggestions? I'm adding this into my CM4 XGO-lite Robot Kit V2 in hopes of making the robot intelligent =)

pi@raspberrypi:~ $ cd /home/pi/DaVinci
pi@raspberrypi:~/DaVinci $ python3 DaVinci.py
Traceback (most recent call last):
  File "/home/pi/DaVinci/DaVinci.py", line 295, in <module>
    wake_word()
  File "/home/pi/DaVinci/DaVinci.py", line 146, in wake_word
    porcupine = pvporcupine.create(keywords=["computer", "jarvis", "DaVinci",],
  File "/home/pi/.local/lib/python3.9/site-packages/pvporcupine/_factory.py", line 69, in create
    return Porcupine(
  File "/home/pi/.local/lib/python3.9/site-packages/pvporcupine/_porcupine.py", line 198, in __init__
    raise self._PICOVOICE_STATUS_TO_EXCEPTION[status](
pvporcupine._porcupine.PorcupineInvalidArgumentError: Initialization failed:
  [0] Keyword file (.ppn) file belongs to a different version of the library. File is `2.2.0` while library is `3.0.0`.
  [1] Loading keyword file at `/home/pi/.local/lib/python3.9/site-packages/pvporcupine/resources/keyword_files/raspberry-pi/DaVinci_raspberry-pi.ppn` failed with `INVALID_ARGUMENT`.

DevMiser, 2023-10-29:
That sounds like a great project!  I would like to see how it comes out.

PicoVoice updated the Porcupine library from 2.2.0 to 3.0.0 a couple of days ago.  I just now uploaded a new version of the keyword file, DaVinci_raspberry_pi.ppn, that is compatible with 3.0.0.  Use that new file and everything should work.

Scitech123, 2023-10-29:
**Thank you so much for making that update to the library!**
Everything is working fine as you can see in this picture.
Next Q for you:
Note that the GPT thinks we are a couple years behind lol. I have another question for you, is there an easy modification to where I can connect this is my specific ChatGPT account? I know we are already using the API, but it's not really pinging the latest and greatest it seems, there's that disconnect such that via my web access to ChatGPT, the computer gets the date correct. It would also be beneficial if I could link with GPT 4 instead. Any ideas to hammer that out?

Once I get this tuned up, the next task will be to make the XGO2 robot's mic and speaker perform the functions. At this time, only raspberrypi is talking and listening via RealVNC access.. the robot its self isn't performing as DaVinci just yet.

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

Scitech123, 2023-10-30:
Getting a new error today:
Traceback (most recent call last):
  File "/home/pi/DaVinci/DaVinci.py", line 276, in <module>
    o = create(
  File "/home/pi/.local/lib/python3.9/site-packages/pvleopard/_factory.py",
line 40, in create
    return Leopard(
  File "/home/pi/.local/lib/python3.9/site-packages/pvleopard/_leopard.py",
line 158, in __init__
    raise self._PICOVOICE_STATUS_TO_EXCEPTION[status]()
pvleopard._leopard.LeopardActivationRefusedError

------------------
(program exited with code: 1)
Press return to continue

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

--

*Love Science & Technology LLC*

2771 Monument Rd. STE 29-312

Jacksonville, FL 32225

*This email message (including attachments) contains information which may
be confidential and/or legally privileged. Unless you are the intended
recipient, you may not use, copy or disclose to anyone the message or any
information contained in the message or from any attachments that were sent
with this email, and If you have received this email message in error,
please advise the sender by email, and delete the message. Unauthorized
disclosure and/or use of information contained in this email may result in
civil and criminal liability.*

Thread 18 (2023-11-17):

Can DaVinci listen other language?

morimori00, 2023-11-17:
I want to make DaVinci be able to listen Japanese prompt.
I thought that by changing something in the line below, Davinci could recognize Japanese instead of English. Even after looking at the PicoVoice documentation, I can't find a way to change the language of SpeechToText. Is there any solution?

DaVinci.py line 153
`def listen():

    cobra = pvcobra.create(access_key=pv_access_key)`

DevMiser, 2023-11-18:
Unfortunately, the language of the speech-to-text cannot be changed at this time. DaVinci uses Picovoice Leopard as its on-device speech-to-text engine.  According to the FAQs on Picovoice's website (https://picovoice.ai/docs/faq/leopard-speech-to-text/): Leopard Speech-to-Text only supports English for now, soon more. Reach out to Picovoice [Sales](https://picovoice.ai/contact/) to tell us about your commercial endeavour if you require support for additional languages. Don’t forget to add the use case, business requirements and project details. Picovoice team will respond to you.

morimori00, 2023-11-20:
Thank you for answering. I'm going to use whisper api instead.
But I think this project is cool and I`ll continue to use DaVinci on my RaspberryPi.

DevMiser, 2023-11-20:
That makes sense.  If you use OpenAI's whisper, you may still want to use Picovoice for wake word and silence detection.  You can train new wake words in Japanese on Picovoice Porcupine (see https://picovoice.ai/platform/porcupine/).  You may also want to use OpenAI's text-to-speech instead of AWS Polly.  I'll post a version of DaVinci that uses that alternative voice engine in the near future.

Closed 2023-11-20.

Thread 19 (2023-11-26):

Picovoice account gets deleted

RetoHB, 2023-11-26:
Picovoice keeps deleting my accounts. This already happened twice, every time about a day after I opened the account.
Anybody having the same issue?

"An account registered with 'xxxxx' has been removed by the Picovoice Audit System. Accounts can be removed in cases of Picovoice Terms of Use violations, such as suspicious activities, creating multiple accounts, or providing false information."

DevMiser, 2023-11-26:
This has never happened to me.

You may want to try to contact Picovoice directly.  I think their email is hello@picovoice.ai.

RetoHB, 2023-11-26:
I tried that, but they are not responding on that email.

EA914, 2024-04-16:
You know, for speech to text you can use OpenAI's whisper model. This would be better in my opinion so you only are hitting one API endpoint.

Check my github repository for a code example. I suggest using this for speech-to-text and transcribe your prompt, send to ChatGPT to get a response, then use OpenAI again for text-to-speech!

DevMiser, 2024-04-16:
Yes, OpenAI's Whisper can be used for the speech to text.  However, you still need to have wake word capability for DaVinci, which Whisper does not provide.  DaVinci currently uses Picovoice Porcupine for detecting its name. Rhasspy may provide another wake word option if you cannot or do not want to use Picovoice.  I prefer the responsiveness of Picovoice for both wake word and speech-to-text on a Raspberry Pi.  And the PicoVoice options are currently free of charge for hobbyists as opposed to OpenAI's now charge per use plan. If you also want to use OpenAI for text-to-speech, you can use the DaVinciAltVoice.py version on this repository.

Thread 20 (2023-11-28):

Nothing happens?

deadsalm0, 2023-11-28:
Hi, thanks for the instructions, i tried to follow them as closely as possibile but nothing happens when i start the program, It Just stays blank for 5 minutes then goes back to the directory.
I'm new to Raspberry so i must be doing something wrong, i'm using a USB headset as microphone/speaker, could this be the problem?
Thank you so much.

fooberton, 2024-01-10:
Hey I'm currently experiencing a similar problem where nothing happens when the program is launched. I think it has something to do with it not recognizing a wake word, so it might be an issue with the microphone or another software issue. Were you able to find a solution?
Thanks in advance!

olskar, 2024-01-10:
Currently investigating the same issue, audio records fine and plays fine so the mic is alright.

Also tried raising mic input with alsamixer but nothing still

DevMiser, 2024-01-11:
@olskar - based upon your other issue with the pygame attribution error, it appears that you got past the "nothing happens" issue?  If so, please share how you did it.
Others - please make certain you follow the additional instructions in the Important - Please Read file on this repository.  Also, in paragraph 6 under Prepare Your Raspberry Pi 4 to Run this Program, please note there are two blank spaces in the above command – one between "mv" and "/home" and one between ".ppn" and "/home". Be sure to include them.
I hope this helps.

olskar, 2024-01-12:
As I first step to investigate for people having "nothing happens" issue I would say instal demo with " sudo pip3 install pvporcupinedemo" and try to run that, it did not work for me.

I then "run porcupine_demo_mic --show_audio_devices" and saw that the default device was wrong.

In the demo it is possible to add argument --audio_device_index to choose device, but I dont think it is possible to choose device in the regular python code.

aplay -L gave me this:
Device 0: Discard all samples (playback) or generate zero samples (capture)

So the DaVinci code is using device 0, and therefore it did not work.

olskar, 2024-01-12:
Or maybe is possible in here?

        recorder = PvRecorder(device_index=-1, frame_length=512)
        recorder.start()

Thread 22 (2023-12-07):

Last step problems

thamm98, 2023-12-07:
Hey DevMiser, having trouble with the very lest step before reboot and run, thoughts?

admin@raspberrypi:~ $ mv /home/admin/DaVinci/DaVinci_raspberry-pi.ppn/home/admin/.local/lib/python3.11/site-packages/pvporcupine/resources/keyword_files/raspberry-pi
mv: missing destination file operand after '/home/admin/DaVinci/DaVinci_raspberry-pi.ppn/home/admin/.local/lib/python3.11/site-packages/pvporcupine/resources/keyword_files/raspberry-pi'
Try 'mv --help' for more information.

Closed 2023-12-08.

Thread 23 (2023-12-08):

trackback error? how would you fix?

thamm98, 2023-12-08:
admin@raspberrypi:~/DaVinci $ python3 DaVinci.py
Traceback (most recent call last):
  File "/home/admin/DaVinci/DaVinci.py", line 302, in <module>
    wake_word()
  File "/home/admin/DaVinci/DaVinci.py", line 153, in wake_word
    porcupine = pvporcupine.create(keywords=keywords,
                ^^^^^^^^^^^^^^^^^^^^^^^^^^^^^^^^^^^^^
  File "/home/admin/.local/lib/python3.11/site-packages/pvporcupine/_factory.py", line 59, in create
    raise ValueError(
ValueError: One or more keywords are not available by default. Available default keywords are:\nalexa, terminator, pico clock, hey siri, porcupine, hey google, grapefruit, hey barista, ok google, computer, picovoice, jarvis, bumblebee, grasshopper, blueberry, americano

Closed 2023-12-09.

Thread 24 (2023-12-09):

API error

thamm98, 2023-12-09:
so close to getting it running, responds with wake word but then says api error

admin@raspberrypi:~ $ cd /home/admin/DaVinci
admin@raspberrypi:~/DaVinci $ python3 DaVinci.py

jarvis detected

Listening...
Voice detected
End of query detected

What would happen if the moon were to disappear.

There was an API error.  Please try again in a few minutes.

pandreas21, 2023-12-18:
I am experiencing the same issue.

DevMiser, 2023-12-18:
If you are a new OpenAI API user, you may have exceeded your free credits.  Please check your OpenAI account.

Also, the installation is not working well with the new Raspberry Pi OS released on December 5, 2023.  For best results, please use a Raspberry Pi 4 (not Raspberry Pi 5) and the legacy OS.  Please refer to the new Important - Please read file on this repository.

SprocketHub, 2024-01-19:
Hi, I followed your guide yesterday using a Pi 4 and the legacy 64bit OS with a brand new unused OpenAI account and I'm having this exact same issue. Do you have any more possible suggestions as to what the cause might be?

DevMiser, 2024-01-22:
Please tell me more about the error so that I can see if I can help.  Are you getting a voice response when you first say "DaVinci".  If not, what is the exact written error that is displayed in your terminal?

SprocketHub, 2024-01-22:
Thank you for responding, originally I got exactly the same error as the original poster of this thread. I also since did the whole process again from scratch (I even reinstalled the OS) but got the same result "There was an API error. Please try again in a few minutes.".

However, after you replied I tried it again to take a picture for you and got a new error -
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

After getting this error I installed everything from scratch again but I'm still getting the new error pictured above.

LavaSlider, 2024-01-23:
I ran into this. The problem was that with a new free OpenAI account you do not have access to GPT-4, change it to `GPT_model = "gpt-3.5-turbo"` and the protocol error goes away. Or better yet, the code can be modified to print the error object when there is an API error for debugging. It can also be modified to look at the error code and type then switch the model to `gpt-3.5-turbo` automatically and ask the user to try again like this:

```
print("\ne.message: ")
print(e.message)
if "model_not_found" == e.code and "invalid_request_error" == e.type:       
        print("It is an invalid_request_error")
        voice("\nThere was an open A I    model not found error with type invalid request. This probably means you do not have access to G P T  4, I will change to G P T three point five turbo. Please try again.")
        GPT_model = "gpt-3.5-turbo" # Try gpt-3.5-turbo to see if it fixes the problem
else:                                       
        voice("\nThere was an open A I  A P I error.  Please try again in a few minutes.")
```

SprocketHub, 2024-01-23:
I changed to gpt-3.5-turbo but still get the same error.

DevMiser, 2024-01-23:
@LavaSlider - Thank you for figuring this out and for the suggested code snippet.

@SprocketHub - Please send a copy of the code change for verification.  Or sign up with OpenAI for a paid account.  With normal usage, you should incur just a few dollars charge per month (much less expensive than ChatGPT Plus).

SprocketHub, 2024-01-26:
Ok so, I've been busy for a few days and just came back to this and it's now working! I bought some credit so that must have been the issue I guess, thank you so much for helping Dev and Lava. I still have one small issue however, I bought a speaker (the exact same one you used by chance) but I'm getting no sound just a text response in the terminal, any ideas?

DevMiser, 2024-01-26:
Are you getting any error messages?

If not, you can enable VNC [https://www.raspberrypi.com/documentation/computers/remote-access.html#vnc] to remotely log into the Raspberry Pi from your computer.  That will allow you to check the audio settings and adjust the volume.  Additionally, this will allow you to keep a terminal open with a chat transcript.

DevMiser, 2024-01-30:
Very happy to hear that you got it working.  Enjoy.

kubbcanada, 2024-03-31:
I just tried this and got the error as well.  Tried the switch to 3.5 turbo and nothing.  I checked my OpenAI and it says I have $18 worth of credit on my free account.  I'm at a loss as to what to try next.

thanks

kubbcanada, 2024-03-31:
> ###
> [Jan 22, 2024](#issuecomment-1905112946)

I added this to my code and it helped greatly.  Thank you!

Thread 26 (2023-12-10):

Tried it on my new Raspberry Pi 5, processor not supported

tmart42, 2023-12-10:
Finished the install on a new Pi 5, and am getting the following traceback:

Traceback (most recent call last):
  File "/home/ty/DaVinci/DaVinci.py", line 8, in <module>
    import pvcobra
  File "/home/ty/.local/lib/python3.11/site-packages/pvcobra/__init__.py", line 12, in <module>
    from ._factory import *
  File "/home/ty/.local/lib/python3.11/site-packages/pvcobra/_factory.py", line 15, in <module>
    from ._util import *
  File "/home/ty/.local/lib/python3.11/site-packages/pvcobra/_util.py", line 64, in <module>
    _PV_SYSTEM, _PV_MACHINE = _pv_platform()
                              ^^^^^^^^^^^^^^
  File "/home/ty/.local/lib/python3.11/site-packages/pvcobra/_util.py", line 57, in _pv_platform
    pv_machine = _pv_linux_machine(platform.machine())
                 ^^^^^^^^^^^^^^^^^^^^^^^^^^^^^^^^^^^^^
  File "/home/ty/.local/lib/python3.11/site-packages/pvcobra/_util.py", line 48, in _pv_linux_machine
    raise NotImplementedError('Unsupported CPU.\n%s' % cpu_info)
NotImplementedError: Unsupported CPU.
processor	: 0
BogoMIPS	: 108.00
Features	: fp asimd evtstrm aes pmull sha1 sha2 crc32 atomics fphp asimdhp cpuid asimdrdm lrcpc dcpop asimddp
CPU implementer	: 0x41
CPU architecture: 8
CPU variant	: 0x4
CPU part	: 0xd0b
CPU revision	: 1

processor	: 1
BogoMIPS	: 108.00
Features	: fp asimd evtstrm aes pmull sha1 sha2 crc32 atomics fphp asimdhp cpuid asimdrdm lrcpc dcpop asimddp
CPU implementer	: 0x41
CPU architecture: 8
CPU variant	: 0x4
CPU part	: 0xd0b
CPU revision	: 1

processor	: 2
BogoMIPS	: 108.00
Features	: fp asimd evtstrm aes pmull sha1 sha2 crc32 atomics fphp asimdhp cpuid asimdrdm lrcpc dcpop asimddp
CPU implementer	: 0x41
CPU architecture: 8
CPU variant	: 0x4
CPU part	: 0xd0b
CPU revision	: 1

processor	: 3
BogoMIPS	: 108.00
Features	: fp asimd evtstrm aes pmull sha1 sha2 crc32 atomics fphp asimdhp cpuid asimdrdm lrcpc dcpop asimddp
CPU implementer	: 0x41
CPU architecture: 8
CPU variant	: 0x4
CPU part	: 0xd0b
CPU revision	: 1

Revision	: d04170
Serial		: 28a0b219c4dec773
Model		: Raspberry Pi 5 Model B Rev 1.0

DevMiser, 2023-12-18:
Unfortunately, the installation does not work well with Raspberry Pi 5 and the new Bookworm OS.  For best results, please use a Raspberry Pi 4 and the legacy OS.

tmart42, 2023-12-19:
Thank you for responding. I did end up setting it up on a legacy 4 after realizing it wouldn't work, and it works like a charm. Thank you!!

Closed 2023-12-19.

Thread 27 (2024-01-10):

AttributeError: module 'pygame' has no attribute 'mixer'

olskar, 2024-01-10:
Not sure what to make of this? It detects the hotword but then pygame has a problem

`pi@raspberrypi:~ $ python3 DaVinci/DaVinci.py

DaVinci detected

Traceback (most recent call last):
  File "/home/pi/DaVinci/DaVinci.py", line 303, in <module>
    voice(random.choice(prompt))
  File "/home/pi/DaVinci/DaVinci.py", line 121, in voice
    pygame.mixer.init()
AttributeError: module 'pygame' has no attribute 'mixer'
^Z
[4]+  Stopped                 python3 DaVinci/DaVinci.py
`

olskar, 2024-01-12:
Solved by running python 3.9 for some reason

Closed 2024-01-12.

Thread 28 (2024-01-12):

Other languages by using Azure instead

olskar, 2024-01-12:
I saw a closed issue about other languages. Would it be possible to implement this by using azure instead, like in the code hear?

https://learn.adafruit.com/robotic-ai-bear-using-chatgpt/code-the-bear

That code use a button instead of wakeword, but does handle other languages.

Davinci uses wakeword, but does not handle other languages.

I tried myself to combine them but my python skills are not good enough.

Would this be possible? :)

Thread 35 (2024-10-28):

Value Error from Pico Porcupine

spatrickhope, 2024-10-28:
Install seemed to work well. Using a Pi4b with the legacy 64bit software download.
I am getting this error upon launching the software:

Traceback (most recent call last):
  File "/home/pi/DaVinci/DaVinci.py", line 302, in <module>
    wake_word()
  File "/home/pi/DaVinci/DaVinci.py", line 153, in wake_word
    porcupine = pvporcupine.create(keywords=keywords,
  File "/home/pi/.local/lib/python3.9/site-packages/pvporcupine/_factory.py", line 59, in create
    raise ValueError(
ValueError: One or more keywords are not available by default. Available default keywords are:\nterminator, blueberry, jarvis, grapefruit, americano, DaVinci.py, porcupine, picovoice, hey siri, computer, pico clock, grasshopper, alexa, bumblebee, hey google, hey barista, ok google

Any idea what is happening here?

Argetlam3, 2024-10-28:
Could you share the keywords list with us? Should be near line 153

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

spatrickhope, 2024-10-28:
> Could you share the keywords list with us? Should be near line 153
> […](#)
> On Mon, 28 Oct 2024 at 17:29, spatrickhope ***@***.***> wrote: Install seemed to work well. Using a Pi4b with the legacy 64bit software download. I am getting this error upon launching the software: Traceback (most recent call last): File "/home/pi/DaVinci/DaVinci.py", line 302, in wake_word() File "/home/pi/DaVinci/DaVinci.py", line 153, in wake_word porcupine = pvporcupine.create(keywords=keywords, File "/home/pi/.local/lib/python3.9/site-packages/pvporcupine/_factory.py", line 59, in create raise ValueError( ValueError: One or more keywords are not available by default. Available default keywords are:\nterminator, blueberry, jarvis, grapefruit, americano, DaVinci.py, porcupine, picovoice, hey siri, computer, pico clock, grasshopper, alexa, bumblebee, hey google, hey barista, ok google Any idea what is happening here? — Reply to this email directly, view it on GitHub <#35>, or unsubscribe <https://github.com/notifications/unsubscribe-auth/BGA4F2CSXVSKQDQFNWWFD4TZ523GDAVCNFSM6AAAAABQYNXITWVHI2DSMVQWIX3LMV43ASLTON2WKOZSGYYTSNRZGY3DINY> . You are receiving this because you are subscribed to this thread.Message ID: ***@***.***>

I started with the default values in line 153 and recieved this error. But then I changed these values as well as the sensitivities 3 lines below to see if those numbers had to match. I figured maybe that was where the Value error was from. Do these numbers have to match with the keywords? Right now I have tried to simplify this to just have a single keyword, but would like to increase these a lot so that my skeleton reacts to almost anything.

   keywords = ["skeleton"]
    porcupine = pvporcupine.create(keywords=keywords,
                            access_key=pv_access_key,
                            sensitivities=[1,], #from 0 to 1.0 - a higher number reduces the miss rate at the cost of increased false alarms
                                   )

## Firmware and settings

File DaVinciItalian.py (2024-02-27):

# the following program is provided by DevMiser - https://github.com/DevMiser

# to use this file, you must download the file porcupine_params_it.pv from
# https://github.com/Picovoice/porcupine/tree/master/lib/common and place it
# in the/home/pi/.local/lib/python3.9/site-packages/pvleopard/lib/common folder 
# on your Raspberry Pi
# You must also download the file leopard_params_it.pv from
# https://github.com/Picovoice/leopard/tree/master/lib/common and place it
# in the /home/pi/.local/lib/python3.9/site-packages/pvleopard/lib/common folder
# on your Raspberry Pi
# You must also create a new wake word in Italian using the Picovoice console
# (https://console.picovoice.ai/), choose Raspberry Pi as the Platform, download the file,
# and put it in the /home/pi/.local/lib/python3.9/site-packages/pvporcupine/resources/keyword_files/raspberry-pi 
# folder on your Raspberry Pi
# In the wake_word() function below, replace "DaVinci" with your new wake word

import datetime
import io
import openai
import os
import pvcobra
import pvleopard
import pvporcupine
import pyaudio
import random
import struct
import sys
import textwrap
import threading
import time

from os import environ
environ['PYGAME_HIDE_SUPPORT_PROMPT'] = '1'
import pygame

from colorama import Fore, Style
from openai import OpenAI
from PIL import Image,ImageDraw,ImageFont,ImageOps,ImageEnhance
from pvleopard import *
from pvrecorder import PvRecorder
from threading import Thread, Event
from time import sleep

import RPi.GPIO as GPIO
GPIO.setwarnings(False)
GPIO.setmode(GPIO.BCM)
led1_pin=18
led2_pin=24
GPIO.setup(led1_pin, GPIO.OUT)
GPIO.output(led1_pin, GPIO.LOW)
GPIO.setup(led2_pin, GPIO.OUT)
GPIO.output(led2_pin, GPIO.LOW)

audio_stream = None
cobra = None
pa = None
porcupine = None
recorder = None
wav_file = None

GPT_model = "gpt-4"
openai.api_key = "put your secret API key between these quotation marks"
pv_access_key= "put your secret access key between these quotation marks"

client = OpenAI(api_key=openai.api_key)

prompt = ["See"]

chat_log=[
    {"role": "system", "content": "Your name is DaVinci. You do not have a namesake. You are a helpful AI-based assistant.  You always respond in Italian."},
    ]

#DaVinci will 'remember' earlier queries so that it has greater continuity in its response
#the following will delete that 'memory' three minutes after the start of the conversation
def append_clear_countdown():
    sleep(180)
    global chat_log
    chat_log.clear()
    chat_log=[
        {"role": "system", "content": "Your name is DaVinci. You do not have a namesake. You are a helpful assistant.  You always respond in Italian."},
        ]    
    global count
    count = 0
    t_count.join

def ChatGPT(query):
    user_query = [
        {"role": "user", "content": query},
        ]         
    send_query = (chat_log + user_query)
    response = client.chat.completions.create(
    model=GPT_model,
    messages=send_query
    )
    answer = response.choices[0].message.content
    chat_log.append({"role": "assistant", "content": answer})
    return answer

def current_time():

    time_now = datetime.datetime.now()
    formatted_time = time_now.strftime("%m-%d-%Y %I:%M %p\n")
    print("The current date and time is:", formatted_time)  

def detect_silence():

    cobra = pvcobra.create(access_key=pv_access_key)

    silence_pa = pyaudio.PyAudio()

    cobra_audio_stream = silence_pa.open(
                    rate=cobra.sample_rate,
                    channels=1,
                    format=pyaudio.paInt16,
                    input=True,
                    frames_per_buffer=cobra.frame_length)

    last_voice_time = time.time()

    while True:
        cobra_pcm = cobra_audio_stream.read(cobra.frame_length)
        cobra_pcm = struct.unpack_from("h" * cobra.frame_length, cobra_pcm)
           
        if cobra.process(cobra_pcm) > 0.2:
            last_voice_time = time.time()
        else:
            silence_duration = time.time() - last_voice_time
            if silence_duration > 1.3:
                print("End of query detected\n")
                GPIO.output(led1_pin, GPIO.LOW)
                GPIO.output(led2_pin, GPIO.LOW)
                cobra_audio_stream.stop_stream                
                cobra_audio_stream.close()
                cobra.delete()
                last_voice_time=None
                break

def fade_leds(event):
    pwm1 = GPIO.PWM(led1_pin, 200)
    pwm2 = GPIO.PWM(led2_pin, 200)

    event.clear()

    while not event.is_set():
        pwm1.start(0)
        pwm2.start(0)
        for dc in range(0, 101, 5):
            pwm1.ChangeDutyCycle(dc)  
            pwm2.ChangeDutyCycle(dc)
            time.sleep(0.05)
        time.sleep(0.75)
        for dc in range(100, -1, -5):
            pwm1.ChangeDutyCycle(dc)                
            pwm2.ChangeDutyCycle(dc)
            time.sleep(0.05)
        time.sleep(0.75)
        
def listen():

    cobra = pvcobra.create(access_key=pv_access_key)

    listen_pa = pyaudio.PyAudio()

    listen_audio_stream = listen_pa.open(
                rate=cobra.sample_rate,
                channels=1,
                format=pyaudio.paInt16,
                input=True,
                frames_per_buffer=cobra.frame_length)

    print("Listening...")

    while True:
        listen_pcm = listen_audio_stream.read(cobra.frame_length)
        listen_pcm = struct.unpack_from("h" * cobra.frame_length, listen_pcm)
           
        if cobra.process(listen_pcm) > 0.3:
            print("Voice detected")
            listen_audio_stream.stop_stream
            listen_audio_stream.close()
            cobra.delete()
            break

def responseprinter(chat):
    wrapper = textwrap.TextWrapper(width=70)  # Adjust the width to your preference
    paragraphs = res.split('\n')
    wrapped_chat = "\n".join([wrapper.fill(p) for p in paragraphs])
    for word in wrapped_chat:
       time.sleep(0.055)
       print(word, end="", flush=True)
    print()

def voice(chat):

    response = client.audio.speech.create(
        model="tts-1",
        voice="echo",
        input=chat
    )

    response.stream_to_file("speech.mp3")
             
    pygame.mixer.init()
    pygame.mixer.music.load("speech.mp3")
    pygame.mixer.music.play()

    while pygame.mixer.music.get_busy():
        pass
    sleep(0.2)
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

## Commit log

2023-06-22 Update DaVinci.py - added code to handle OpenAI errors
    [DaVinci.py]
2023-06-22 Update DaVinci.py - OpenAI error handling correction
    [DaVinci.py]
